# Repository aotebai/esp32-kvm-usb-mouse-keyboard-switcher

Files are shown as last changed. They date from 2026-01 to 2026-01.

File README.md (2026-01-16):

# ESP32-S3 KVM Switch (Dual-Device Keyboard & Mouse Sharing)

## 🌐 Language Switch
- [🔤 English Version (Current)](./README.md)
- [📝 中文版本](./docs/README_zh.md)

---
## 🔤 English-version
### 🚩Project Introduction
A dual-device KVM switch based on ESP32-S3 and CH9350 modules, which enables seamless sharing of a single set of keyboard and mouse between two computers. Equipped with ESP32-S3 on-board RGB-LED light effects to indicate the working status, no driver installation is required, and users without development experience can flash the precompiled firmware with one click. It supports dual-device power supply redundancy design to ensure stable system operation when a single device is powered on.
### ✨Key Features

- Dual-device switching: Supports fast switching of keyboard and mouse between 2 computers (shares one set of keyboard and mouse)
- Two switching methods: Mouse middle button (can be disabled via the K2 button of the 3-position microswitch) or K1 button of the 3-position microswitch
- LED effect indication: Three non-repeating colors of the LED flash in sequence during switching; a blue breathing light indicates Host A, and a red breathing light indicates Host B, with no flicker or abnormal extinction
- Complete core functions: Keyboard and mouse DMA transparent transmission, mouse middle button switching, K1 button switching of the 3-position microswitch, K2 button (on/off) for the mouse middle button function, K3 button short press to control the LED, long press to reset, and no functional degradation after standing idle
- Redundant power supply design: Achieves dual-device power supply mutual backup through Schottky diodes, ensuring stable system operation when a single device is powered on
- ESP-IDF compatibility: Compatible with ESP-IDF v5.5.1, no third-party dependencies, and only uses natively compatible APIs for stable operation
- Driver-free compatibility: Supports all operating systems (Windows/Mac/Linux) that support the USB HID protocol
- One-click flashing: Provides precompiled firmware, no need to build an ESP-IDF development environment

### 🛠️ Hardware List
| Hardware Name | Taobao Link | Quantity | Unit Price (CNY) | Total Amount (CNY) | Shipping Fee (CNY) | Grand Total (CNY) |
|:---:|:---:|:---:|:---:|:---:|:---:|:---:|
| ESP32 S3 Core Board (1-N16R8) | [ESP32 S3 Core Board Link](https://item.taobao.com/item.htm?id=715306783664) | 1 | 24.1 | 24.1 | 0 | 24.1 |
| CH9350 Module | [CH9350 Module Link](https://item.taobao.com/item.htm?id=695173316772) | 3 | 18.5 | 55.5 | 3 | 58.5 |
| 3-position Microswitch (with K1/K2/K3 Buttons) | [3-position Microswitch Link](https://item.taobao.com/item.htm?id=550176517768) | 1 | 3.88 | 3.88 | 0 | 3.88 |
| USB OTG Cable (Male to Male) | [USB OTG Cable Link](https://item.taobao.com/item.htm?id=550176517768) | 6 | 0.85 | 5.1 | 2 | 7.1 |
| Through-hole Schottky Diode DO-41 (1N5819 1A 40V) | [Through-hole Schottky Link](https://detail.tmall.com/item.htm?id=781535844592) | 20(use2) | 1.7 | 1.7 | 0 | 1.7 |
| 304 Stainless Steel Pan Head Screw and Nut Set(M2.5x8) | [Head Screw and Nut Set Link](https://detail.tmall.com/item.htm?id=637072501037) | 50(use14) | 4.7 | 4.7 | 0 | 4.7 |
| 3D Printed Case | [3D Printed Case Link](https://www.jlc-3dp.cn/fp/Amntaau/1) | 1 | 24.78 | 24.78 | 3.2 | 27.98 |

### 🔌 Wiring & Assembly

1.Connect the keyboard and mouse to the corresponding USB ports of the CH9350 module respectively

2.Connect the CH9350 module UART port (Host A) to ESP32-S3: TXD→U0RX (GPIO10), RXD→U0TX (GPIO11), GND→GND, 5V→1N5819→5V (ensure stable power supply)

3.Connect the CH9350 module UART port (Host B) to ESP32-S3: TXD→U2RX (GPIO44), RXD→U2TX (GPIO43), GND→GND, 5V→1N5819→5V (ensure stable power supply)

4.Wire the 3-position microswitch: Connect the K1/K2/K3 buttons to the corresponding GPIO pins of the ESP32-S3 respectively

5.Schottky diodes: The anodes of the two diodes are connected to the 5V pins of Host A and Host B respectively, and the cathodes are connected to the 5Vin of ESP32S3 and the 5V pin of Slave C (to ensure effective power supply when one computer is powered on and the entire system can run normally)

6.Organize all components and assemble them into the 3D printed case, fix them firmly to avoid poor contact

#### Wiring Diagrams
##### 1. Power Supply Wiring

      [Host A]                       [Host B]
          |                               |
        5V_OUT                           5V_OUT
          |                               |
          +-----> [D1] +-----+            +-----> [D2] +-----+
          |       (1N5819)   |            |       (1N5819)   |
          |       DO-41      |            |       DO-41      |
          |                  |            |                  |
          +------------------+------------+------------------+
                             |
                        [System 5V Bus]
                             |
                  +----------+-----------+
                  |                      |
            [ESP32S3]                [Slave C]
            5V (Vin)                 5V_IN
           
       [ESP32S3]   [Host A]   [Host B]   [Slave C]   [Microswitch]
          GND ------ GND ------- GND ------- GND ------ GND

##### 2. UART & Control Wiring
       [ESP32S3]                  [Host A]
       U0TX (GPIO11) ------------> RXD
       U0RX (GPIO10) <------------ TXD
       
       [ESP32S3]                  [Host B]
       U2TX (GPIO43) ------------> RXD  
       U2RX (GPIO44) <------------ TXD
       
       [ESP32S3]                  [Slave C]
       U1TX (GPIO17) ------------> TXD  
       U1RX (GPIO18) <------------ RXD
       
       [ESP32S3]                  [Microswitch]
       GPIO12 -------------------->(K1) 
       GPIO13 -------------------->(K2) 
       GPIO14 -------------------->(K3) 

### 🚀 One-Click Flashing (No ESP-IDF Required)
#### For Windows Users

1. Download the Espressif ESP Flash Download Tool (recommended to get the latest version from the official website):
   - 🔗 [Official ESP Flash Download Tool](https://docs.espressif.com/projects/esp-test-tools/en/latest/esp32/production_stage/tools/flash_download_tool.html)
   - 📦 [Local Mirror (flash_download_tool.zip)](./firmware/tools/flash_download_tool.zip) (for faster access, same as official latest version)
2. Connect the ESP32-S3 development board to the computer via a USB cable, and select the corresponding COM port (install the dedicated ESP32-S3 USB driver if it is not recognized)
3. Set the flashing parameters: 80MHz / DIO / 2MB (strictly correspond to the firmware configuration to avoid flashing failure)
4. Add firmware files and corresponding flashing addresses:
        - bootloader.bin @ 0x0
        - partition-table.bin @ 0x8000
        - ch9350_led_switch.bin @ 0x10000
5. Click the "START" button on the tool interface to start flashing, and wait for the progress bar to complete (the prompt "FINISH" indicates success)

For detailed address description and parameter verification: firmware/precompiled/flash_addresses.md
### 🎮 How to Use

1. Connect the ESP32-S3 to two target computers via USB cables respectively, ensuring the computers recognize the device normally (no driver prompt is required)
2. Device switching: Press the "mouse middle button" or "K1 button of the 3-position microswitch", the LED will flash three colors in sequence, and the corresponding host breathing light will turn on after completion (blue for Host A, red for Host B)
3. Mouse middle button function control: Press the "K2 button" to switch the on/off status of the mouse middle button switching function (it is recommended to use an LED indicator to distinguish the on/off status)
4. LED control and reset: Short press the "K3 button" to manually control the LED on/off; long press the "K3 button" for more than 3 seconds to reset the device to the initial state

### 🎨 3D Case & PDF Files

 - 3D Models: 3d_models/ (including FreeCAD source files and STL printing files, which can be directly used for 3D printing)
 - 2D Drawings: PDF_drawing/ (PDF formats, which can be used for Wiring Diagrams)

3D Case Rendering:

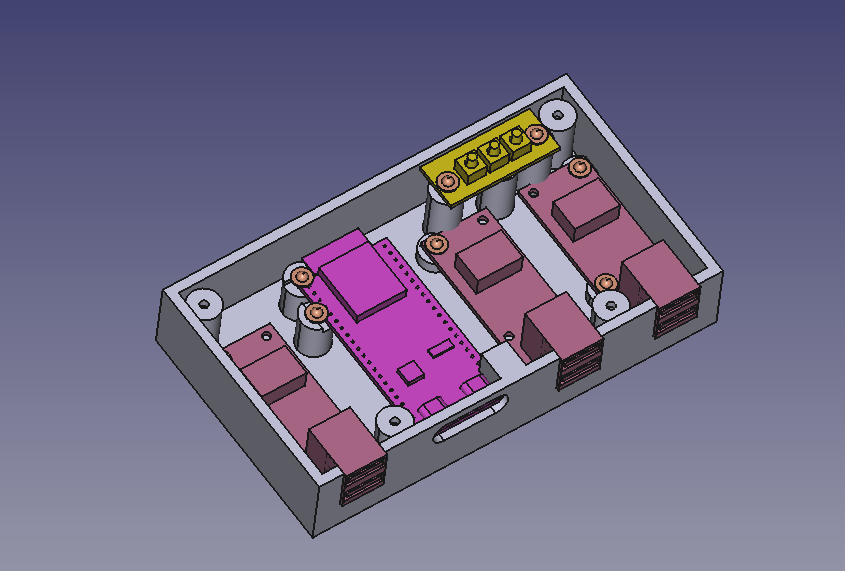
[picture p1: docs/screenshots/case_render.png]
3D Case Rendering


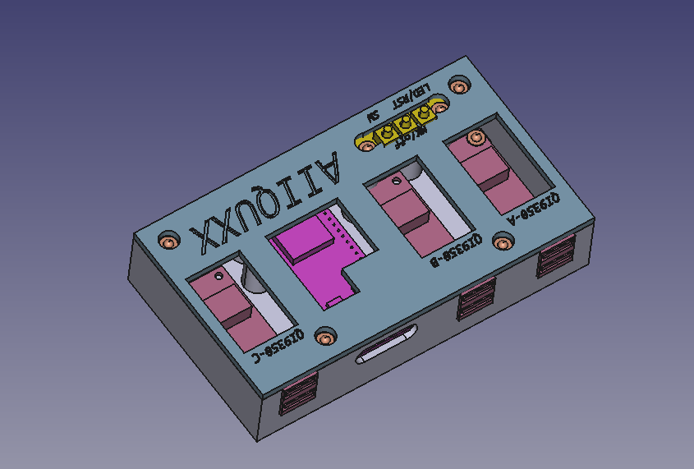
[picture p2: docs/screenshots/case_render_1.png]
3D Case Rendering_1


physical image:

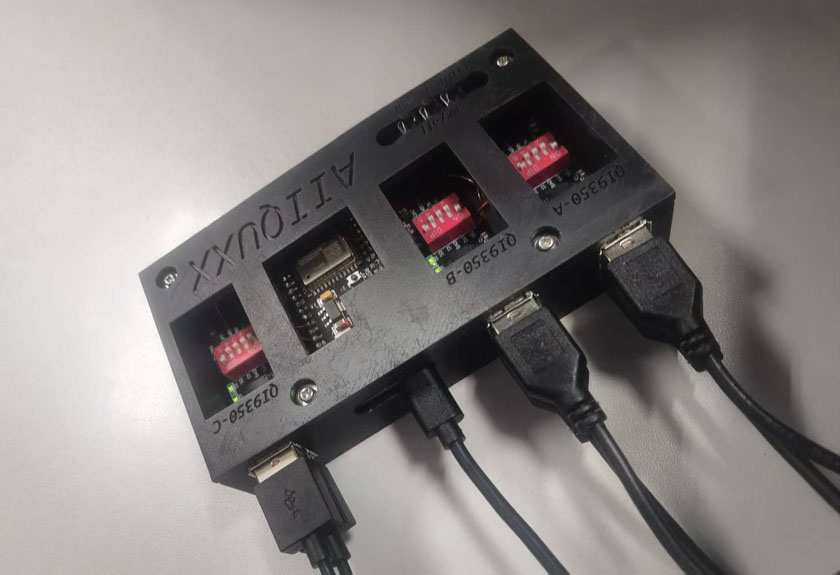
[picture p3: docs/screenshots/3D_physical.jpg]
physical image

### 🔨 Build from Source (For Developers)

1. Install ESP-IDF v5.5.1 (strictly correspond to the version to avoid compatibility issues)
2. clone repositoryto locate:    `git clone https://github.com/aotebai/esp32-kvm-usb-mouse-keyboard-switcher.git`
3. Enter the project directory and execute the following commands to compile and flash:
```bash
idf.py set-target esp32s3
idf.py build
idf.py -p /dev/ttyUSB0 flash monitor
```
### ❓ Frequently Asked Questions (FAQ)
Q1: Flashing failed / COM port not recognized

A: Install the corresponding USB driver for ESP32-S3; replace with a high-quality USB cable (avoid data cables that only charge without transmitting data); replace the USB port of the computer; ensure the development board enters download mode (operate according to the corresponding key combination).

Q2: No response after assembly, LED not on

A: Check the wiring (especially the power supply line and UART connection, avoid reversing pins); verify that the firmware flashing address is correct; ensure the CH9350 module receives stable 5V power supply and the ESP32-S3 power supply voltage is normal; check if the diode is reversed.

Q3: Switching function is normal, but the keyboard and mouse are not recognized by the computer

A: Confirm that the target computer recognizes the ESP32-S3 as a USB HID device (can be viewed in Device Manager); replace the USB port or USB cable of the computer; update to the latest version of the project firmware, and check whether the communication between the CH9350 module and ESP32-S3 is normal.

Q4: Abnormal LED light effects (flicker, wrong color)

A: Check whether the LED wiring is firm and the pins are corresponding correctly; confirm that the LED control logic in the firmware is consistent with the hardware wiring; try replacing the faulty LED.

Q5: The system cannot work when a single computer is powered on

A: Check if the diode wiring direction is correct (anode connected to host 5V, cathode connected to system bus); confirm that the diode model is 1N5819 (to ensure low forward conduction voltage); check if there is poor contact in the power supply line.

### 📺 Demo Video
Bilibili Demo Link (Waiting...)
### 📄 Open Source License
Apache License 2.0 ,See the [LICENSE](/LICENSE) file in the root directory for details.

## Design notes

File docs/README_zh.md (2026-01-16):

# ESP32-S3 KVM 切换器（双设备键鼠共享）

## 🌐 语言切换
- [📝 中文版本 (当前)](./docs/README_zh.md)
- [🔤 English Version](../README.md)

---

## 📝  中文版本

### 🚩 项目介绍
一款基于 ESP32-S3 和 CH9350 模块的双设备 KVM 切换器，可实现一套键鼠无缝共享给两台电脑，搭配ESP32-S3板载RGB-LED 灯光特效指示工作状态，无需安装驱动，无开发经验用户也可通过预编译固件一键烧录使用。支持双设备供电冗余设计，确保单设备开机时系统仍能稳定运行。

### ✨ 核心功能
- 双设备切换：支持 2 台电脑之间的键鼠快速切换（共享一套键盘和鼠标）
- 两种切换方式：鼠标中键（可通过三位微动开关的K2键禁用）或三位微动开关 K1 键
- 灯光特效指示：切换时 LED 三种不重复的颜色顺序爆闪、 蓝色呼吸灯特效指示上位机 A，红色呼吸灯特效指示上位机 B，无频闪、无熄灭异常
- 核心功能完整：键鼠 DMA 透传，鼠标中键切换，三位微动开关 K1 键切换，K2键（开/关）鼠标中间键功能，K3键短按控制 LED、长按复位，静置后无功能衰减
- 供电冗余设计：通过肖特基二极管实现双设备供电互备，单设备开机即可保障系统正常运行
- 开发环境兼容：兼容 ESP-IDF v5.5.1，无第三方依赖，仅使用原生兼容 API，运行稳定
- 免驱兼容：支持所有支持 USB HID 协议的操作系统（Windows/Mac/Linux）
- 一键烧录：提供预编译固件，无需搭建 ESP-IDF 开发环境

### 🛠️ 硬件清单
| 硬件名称 | 购买链接 | 数量 | 单价(元) | 金额(元) | 快递费(元) | 合计(元) |
|---|---|---|---|---|---|---|
| ESP32 S3 核心板（1-N16R8） | [ESP32 S3 核心板](https://item.taobao.com/item.htm?id=715306783664) | 1 | 24.1 | 24.1 | 0 | 24.1 |
| CH9350 模块 | [CH9350 模块](https://item.taobao.com/item.htm?id=695173316772) | 3 | 18.5 | 55.5 | 3 | 58.5 |
| 三位微动开关（含 K1/K2/K3 按键） | [三位微动开关](https://item.taobao.com/item.htm?id=550176517768) | 1 | 3.88 | 3.88 | 0 | 3.88 |
| USB OTG 线 (公对公) | [USB OTG 线](https://item.taobao.com/item.htm?id=550176517768) | 6 | 0.85 | 5.1 | 2 | 7.1 |
| 直插肖特基二极管DO-41(1N5819 1A 40V) | [直插肖特基二极管](https://detail.tmall.com/item.htm?id=781535844592) | 20(使用2个) | 1.7 | 1.7 | 0 | 1.7 |
| 304不锈钢十圆头螺丝螺母套装 (M2.5x8)| [圆头螺丝螺母套装](https://detail.tmall.com/item.htm?id=637072501037) | 50(使用14个) | 4.7 | 4.7 | 0 | 4.7 |
| 3D打印外壳 | [3D打印](https://www.jlc-3dp.cn/fp/Amntaau/1) | 1 | 24.78 | 24.78 | 3.2 | 27.98 |

### 🔌 接线与组装
1. 将键盘、鼠标分别连接至 CH9350 模块的对应 USB 接口
2. CH9350模块 UART口(上位机A) 与 ESP32-S3 连接：TXD→U0RX (GPIO10)、RXD→U0TX (GPIO11) 、GND→GND、5V→1N5819→5V（确保供电稳定）
3. CH9350模块 UART口(上位机B) 与 ESP32-S3 连接：TXD→U2RX (GPIO44)、RXD→U2TX (GPIO43) 、GND→GND、5V→1N5819→5V（确保供电稳定）
4. 三位微动开关接线：K1/K2/K3 按键分别连接至 ESP32-S3 对应的 GPIO 引脚
5. 肖特基二极管:两个二极管正极分别接上位机A、上位机B的5V引脚，负极接ESP32S3的5Vin和下位机C的5V引脚(确保在一台计算机开机的情况下有效供电，整个系统能正常运行)
6. 将所有部件整理后，组装至 3D 打印外壳中，固定牢固避免接触不良

#### 接线示意图
##### 1. 电源部分接线

       [上位机 A]                       [上位机 B]
          |                               |
        5V_OUT                           5V_OUT
          |                               |
          +-----> [D1] +-----+            +-----> [D2] +-----+
          |       (1N5819)   |            |       (1N5819)   |
          |       DO-41      |            |       DO-41      |
          |                  |            |                  |
          +------------------+------------+------------------+
                             |
                        [系统 5V 总线]
                             |
                  +----------+-----------+
                  |                      |
            [ESP32S3]                [下位机 C]
            5V (Vin)                 5V_IN
            
       [ESP32S3]   [上位机 A]   [上位机 B]   [下位机 C]   [微动开关]
          GND ------ GND ------- GND ------- GND ------ GND

    两个二极管正极分别接上位机 A、上位机 B 的 5V 引脚，负极汇接到系统 5V 总线
    系统 5V 总线为 ESP32S3 和下位机 C 供电，确保单台计算机开机时系统仍能正常运行

##### 2. 串口与控制部分接线

       [ESP32S3]                  [上位机 A]
       U0TX (GPIO11) ------------> RXD
       U0RX (GPIO10) <------------ TXD
       
       [ESP32S3]                  [上位机 B]
       U2TX (GPIO43) ------------> RXD  
       U2RX (GPIO44) <------------ TXD
       
       [ESP32S3]                   [下位机 C]  
       U1TX (GPIO17) ------------> TXD 
       U1RX (GPIO18) <------------ RXD

       [ESP32S3]                   [微动开关]
       GPIO12 -------------------->(K1) 
       GPIO13 -------------------->(K2) 
       GPIO14 -------------------->(K3) 

### 🚀 一键烧录（无需 ESP-IDF）
#### 适用于 Windows 用户
1. 下载乐鑫 ESP Flash Download Tool（选择对应系统版本，建议下载最新版）：
   - 🔗 [官方下载地址](https://docs.espressif.com/projects/esp-test-tools/zh_CN/latest/esp32/production_stage/tools/flash_download_tool.html)
   - 📦 [本地镜像（flash_download_tool.zip）](../firmware/tools/flash_download_tool.zip)（国内用户快速下载，与官方最新版一致）

2. 将 ESP32-S3 开发板通过 USB 线连接电脑，选择对应的 COM 口（未识别请安装 ESP32-S3 专用 USB 驱动）
3. 设置烧录参数：`80MHz` / `DIO` / `2MB`（严格对应固件配置，避免烧录失败）
4. 添加固件文件并对应烧录地址：
    - `bootloader.bin` @ `0x0`
    - `partition-table.bin` @ `0x8000`
    - `ch9350_led_switch.bin` @ `0x10000`
5. 点击工具界面「START」按钮开始烧录，等待进度条完成（提示“FINISH”即为成功）

详细地址说明及参数核对：`firmware/precompiled/flash_addresses.md`

### 🎮 使用方法
1. 通过 USB 线将 ESP32-S3 分别连接至两台目标电脑，确保电脑正常识别设备（无驱动提示即可）
2. 设备切换：按下「鼠标中键」或「三位微动开关 K1 键」，LED 三种颜色顺序爆闪，完成后对应上位机呼吸灯亮起（蓝色为上位机 A，红色为上位机 B）
3. 鼠标中键功能控制：按下「K2 键」可切换鼠标中键切换功能的开启/关闭（建议搭配 LED 指示灯区分开关状态）
4. LED 控制与复位：短按「K3 键」可手动控制 LED 灯光开关；长按「K3 键」3 秒以上，设备复位至初始状态

### 🎨 3D 外壳与 PDF 图纸
- 3D 模型：`3d_models/`（含 FreeCAD 源文件及 STL 打印文件，可直接用于 3D 打印）
- 2D 平面图：`PDF_drawing/`（PDF格式，可用于串口与控制部分接线）

3D 外壳渲染图：

3D 外壳渲染图

3D 外壳渲染图_1

实物图：

实物图
### 🔨 从源码编译（开发者专用）
1. 安装 ESP-IDF v5.5.1 版本（严格对应版本，避免兼容性问题）
2. 克隆本仓库至本地：`git clone https://github.com/aotebai/esp32-kvm-usb-mouse-keyboard-switcher.git`
3. 进入项目目录，执行以下命令编译、烧录：
```bash
idf.py set-target esp32s3
idf.py build
idf.py -p /dev/ttyUSB0 flash monitor
```

### ❓ 常见问题（FAQ）
Q1：烧录失败 / 无法识别 COM 口

A：安装 ESP32-S3 对应 USB 驱动；更换优质 USB 线（避免数据线仅充电不传输数据）；更换电脑 USB 端口；确保开发板进入下载模式（按对应按键组合操作）。

Q2：组装后设备无响应、LED 不亮

A：检查接线（尤其是供电线路和 UART 串口连接，避免接反引脚）；验证固件烧录地址是否正确；确保 CH9350 模块获得稳定 5V 供电，ESP32-S3 供电电压正常；检查二极管方向是否接反。

Q3：切换功能正常，但键鼠无法被电脑识别

A：确认目标电脑将 ESP32-S3 识别为 USB HID 设备（设备管理器中可查看）；更换电脑 USB 端口或 USB 线；更新至项目最新版本固件，检查 CH9350 模块与 ESP32-S3 通信是否正常。

Q4：LED 灯光特效异常（频闪、颜色错误）

A：检查 LED 灯珠接线是否牢固、引脚对应正确；确认固件中 LED 控制逻辑与硬件接线一致；更换故障 LED 灯珠尝试。

Q5：单台电脑开机时系统无法工作

A：检查二极管接线方向是否正确（正极接上位机 5V，负极接系统总线）；确认二极管型号为 1N5819（确保正向导通压降低）；检查供电线路是否存在接触不良。

### 📺 演示视频
B 站演示链接（正在制作中...）
### 📄 开源协议
Apache License 2.0, 详见根目录 [LICENSE](../LICENSE) 文件。

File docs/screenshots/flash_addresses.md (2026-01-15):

# ESP32-S3 Flash Burn Addresses
## 📋 Core Flash Burn Address List (Mandatory)
|Firmware File Name | Corresponding Burn Address | Notes |
|---|---|---|
|bootloader.bin | 0x0 | Bootloader, essential for ESP32-S3 startup |
|partition-table.bin | 0x8000 | Partition table, defines storage ranges for firmware, data, and other partitions |
|ch9350_led_switch.bin | 0x10000 | Project core firmware (implements KVM switch functionality) |
|nvs_partition.bin (Optional) | 0x9000 | NVS (Non-Volatile Storage) partition, used to save device configuration parameters|
## ⚙️ Mandatory Flash Burn Parameter Configuration
In addition to matching the addresses, the following parameters must also be consistent; otherwise, it will result in flash failure or device startup failure:

1. Crystal Oscillator Frequency: 80MHz (Recommended default value for ESP32-S3, do not change to 40MHz)
2. Flash Mode: DIO (Compatible with most ESP32-S3 development board flash memory, avoid using QIO mode)
3. Flash Size: 2MB (If your development board has 4MB/8MB flash memory, you can select the corresponding size, and the partition table needs to be adapted synchronously)
4. Baud Rate: 115200 (Stable transmission; excessively high baud rate may cause transmission errors, while excessively low baud rate will result in long flash time)

## 🚨 Important Notes

1.  The burn addresses of all firmware files cannot be modified arbitrarily; they must be consistent with the partition table configuration during compilation, otherwise the device cannot start normally.
2.  If you recompile the firmware using ESP-IDF, ensure that the addresses in the partition.csv partition table file are consistent with this document.
3.  During flashing, follow the sequence of "select the address first → then add the corresponding firmware file" to avoid mismatching files and addresses.
4.  If you receive prompts such as "startup failure" or "partition table error" after flashing, first check whether the address configuration and flash size parameters are correct.

## 📎 Related Documents

    ESP32-S3 Official Partition Table Documentation
    Project Flashing Tutorial: Root directory README.md (English) / docs/README_zh.md (Chinese)

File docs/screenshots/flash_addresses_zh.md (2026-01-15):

# ESP32-S3 Flash Burn Addresses (烧录地址说明)
## 📋 核心烧录地址清单（必看）
| 固件文件名称 | 对应烧录地址 | 备注说明 |
|---|---|---|
| `bootloader.bin` | `0x0` | 引导加载程序，ESP32-S3 启动必备 |
| `partition-table.bin` | `0x8000` | 分区表，定义固件、数据等分区的存储范围 |
| `ch9350_led_switch.bin` | `0x10000` | 项目核心固件（KVM 切换器功能实现） |
| `nvs_partition.bin`（可选） | `0x9000` | NVS 非易失性存储分区，用于保存设备配置参数 |

## ⚙️ 必选烧录参数配置
除了地址匹配，还需确保以下参数一致，否则会导致烧录失败或设备无法启动：
1.  **晶振频率**：`80MHz`（ESP32-S3 推荐默认值，不可改为 40MHz）
2.  **闪存模式**：`DIO`（兼容大多数 ESP32-S3 开发板闪存，避免使用 QIO 模式）
3.  **闪存大小**：`2MB`（若你的开发板闪存为 4MB/8MB，可选择对应大小，分区表需同步适配）
4.  **波特率**：`115200`（稳定传输，过高易出现传输错误，过低烧录耗时过长）

## 🚨 注意事项
1.  所有固件文件的烧录地址**不可随意修改**，必须与编译时的分区表配置一致，否则设备无法正常启动；
2.  若使用 ESP-IDF 重新编译固件，需确保 `partition.csv` 分区表文件中的地址与本文档一致；
3.  烧录时需按「先选择地址 → 再添加对应固件文件」的顺序操作，避免文件与地址不匹配；
4.  若烧录后提示「启动失败」「分区表错误」，优先检查地址配置和闪存大小参数是否正确。

## 📎 关联文档
- [ESP32-S3 官方分区表说明](https://docs.espressif.com/projects/esp-idf/en/latest/esp32s3/api-guides/partition-tables.html)
- 项目烧录教程：根目录 `README.md`（英文）/ `docs/README_zh.md`（中文）

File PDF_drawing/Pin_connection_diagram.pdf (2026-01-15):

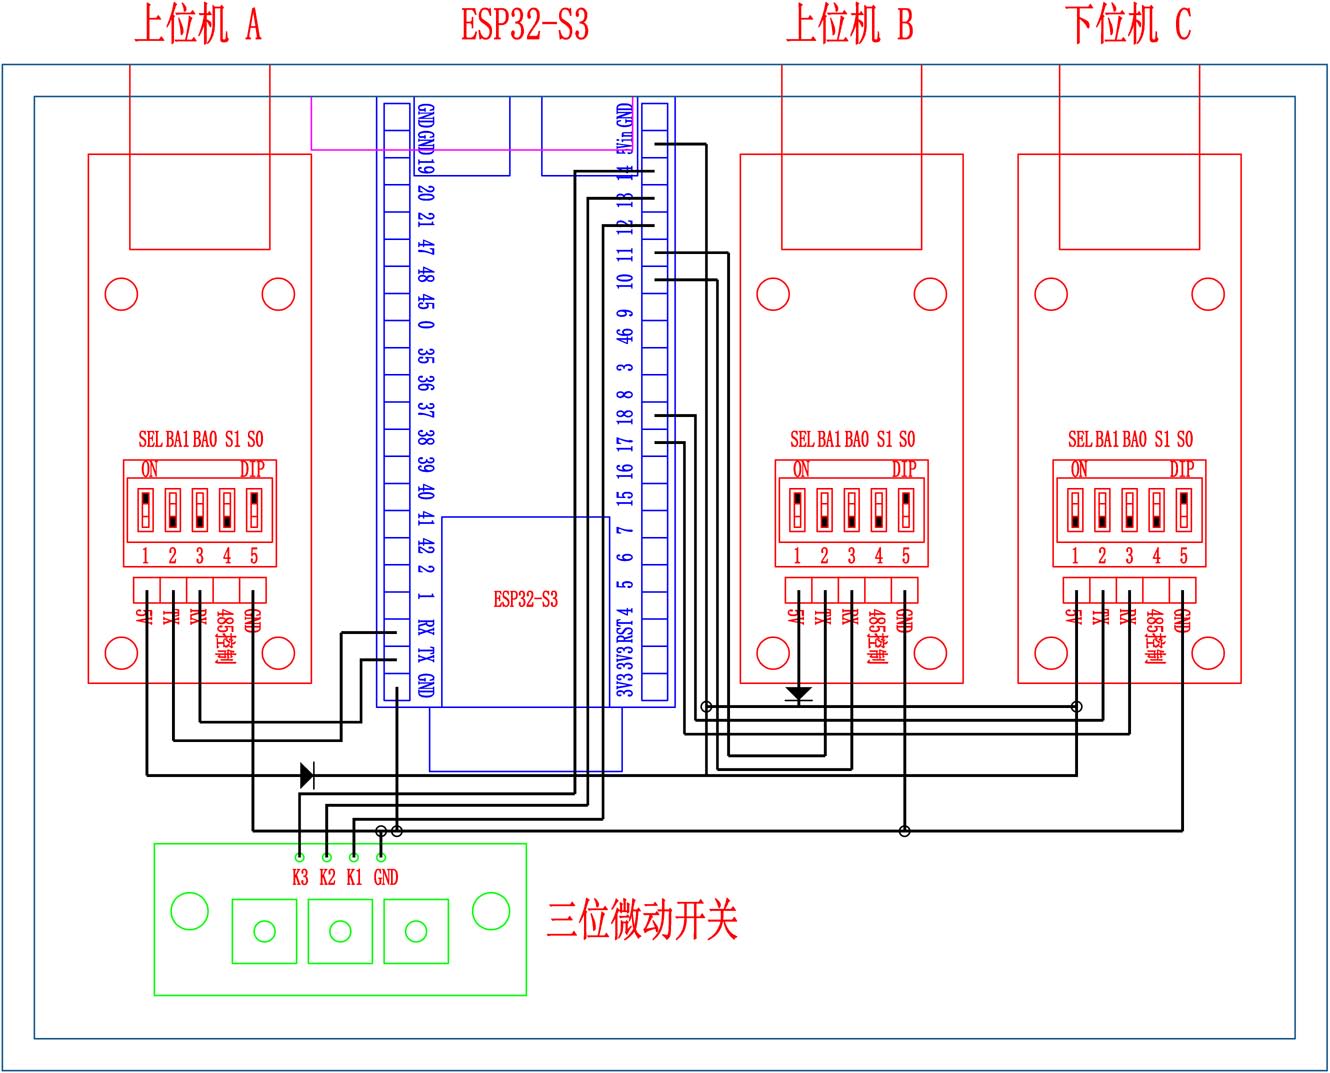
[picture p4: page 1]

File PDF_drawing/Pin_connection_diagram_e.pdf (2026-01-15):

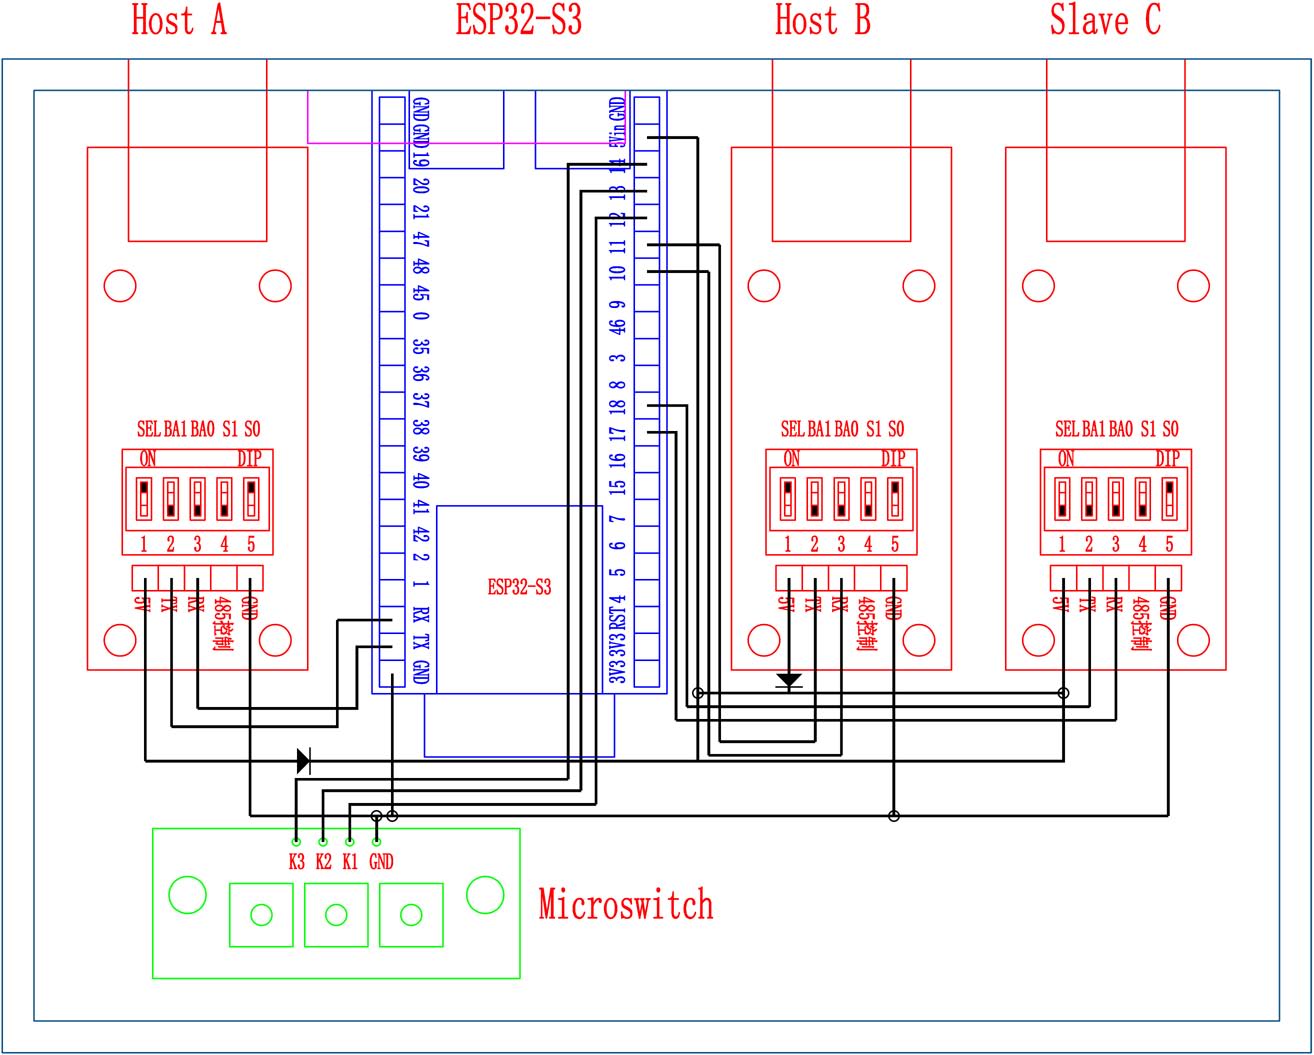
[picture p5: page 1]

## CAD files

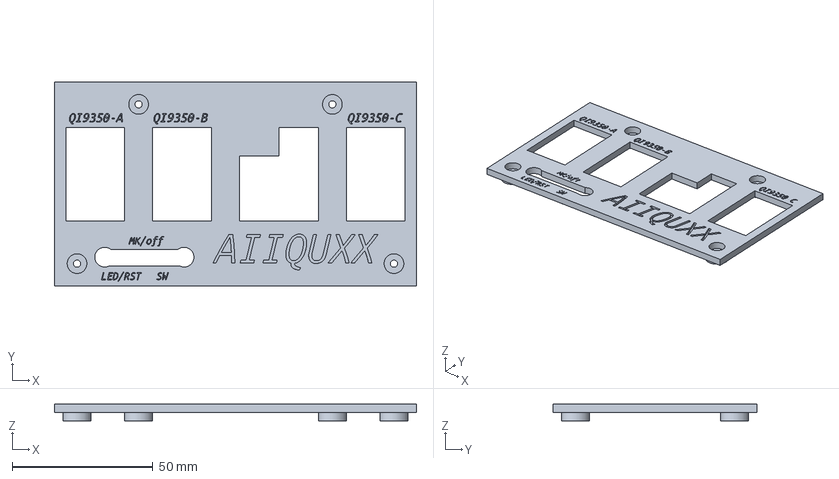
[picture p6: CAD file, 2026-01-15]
3d_models/box_cover_1.FCStd
128.5 x 72.5 x 6.00 mm

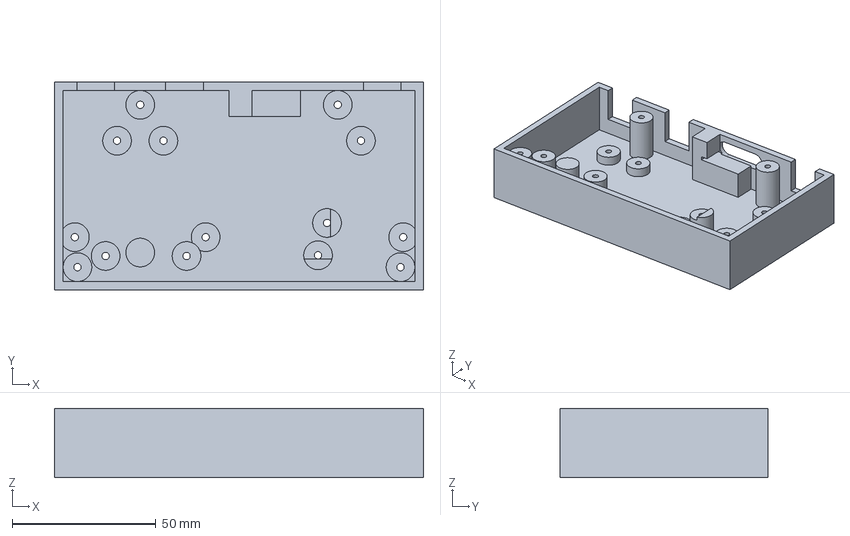
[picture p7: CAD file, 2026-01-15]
3d_models/box.FCStd
128.5 x 72.6 x 24.1 mm

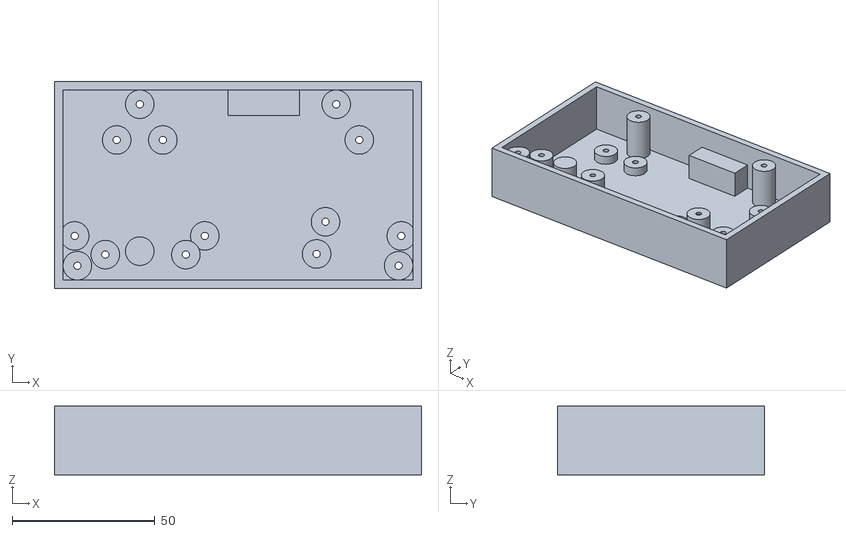
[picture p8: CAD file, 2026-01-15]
3d_models/box-Pocket008 (Meshed).stl
128.5 x 72.6 x 24.1

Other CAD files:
3d_models/box_cover_1-Pocket008 (Meshed)001.stl

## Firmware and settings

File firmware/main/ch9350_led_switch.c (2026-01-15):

#include <stdio.h>
#include <string.h>
#include <math.h>
#include "freertos/FreeRTOS.h"
#include "freertos/task.h"
#include "freertos/semphr.h"
#include "driver/uart.h"
#include "driver/gpio.h"
#include "driver/rmt.h"
#include "esp_log.h"
#include "esp_timer.h"
#include "esp_random.h"
#include "esp_system.h"
#include "esp_rom_sys.h" // 新增：硬件延时头文件

// ==================== 核心配置参数 ====================
// UART配置
#define BAUD_RATE          115200
#define FRAME_LENGTH       7
#define SWITCH_LOCKOUT_MS  1500

// DMA配置
#define UART_DMA_BUFF_SIZE     256
#define UART_DMA_RX_TIMEOUT    1
#define UART_DMA_RX_THRESHOLD  (UART_DMA_BUFF_SIZE / 2)

// UART端口与引脚
#define UART_LOWER_NUM     UART_NUM_1
#define UART_UPPER_A_NUM   UART_NUM_0
#define UART_UPPER_B_NUM   UART_NUM_2

#define UART_LOWER_TXD     17
#define UART_LOWER_RXD     18
#define UART_UPPER_A_TXD   11
#define UART_UPPER_A_RXD   10
#define UART_UPPER_B_TXD   43
#define UART_UPPER_B_RXD   44

// 微动开关引脚
#define K1_GPIO            12
#define K2_GPIO            13
#define K3_GPIO            14

// K3长按复位配置
#define K3_LONG_PRESS_MS   3000    // 长按3秒触发复位
#define K3_DEBOUNCE_MS     50      // 消抖时间

// 鼠标中键帧解析
#define MOUSE_FRAME_HEADER1 0x57
#define MOUSE_FRAME_HEADER2 0xAB
#define MOUSE_OPCODE       0x02
#define MOUSE_BUTTON_BYTE  3
#define MIDDLE_BUTTON_BIT  2

// WS2812配置
#define LED_STRIP_GPIO_PIN         48
#define LED_STRIP_LED_COUNT        1
#define RMT_RESOLUTION_HZ          10000000
#define RMT_CHANNEL                RMT_CHANNEL_0

// 爆闪参数
#define BURST_TIMES_PER_COLOR      10
#define BURST_FLASH_PERIOD_US      80000
#define BURST_ON_US                40000
#define PAUSE_MS_BETWEEN_COLOR     50
#define BURST_SELECT_COLOR_NUM     3

// 呼吸灯参数
#define BREATH_FREQ_PER_MIN        7.5f
#define BREATH_PERIOD_MS           (uint32_t)(2 * 60 * 1000 / BREATH_FREQ_PER_MIN)
#define BREATH_STEP_MS             10
#define BREATH_MAX_BRIGHTNESS      155
#define BREATH_SMOOTH_FACTOR       2.0f
#define BREATH_DARK_OFF_MS         500

// WS2812时序
#define WS2812_T0H_TICKS           (uint16_t)(0.4 * RMT_RESOLUTION_HZ / 1000000)
#define WS2812_T0L_TICKS           (uint16_t)(0.85 * RMT_RESOLUTION_HZ / 1000000)
#define WS2812_T1H_TICKS           (uint16_t)(0.8 * RMT_RESOLUTION_HZ / 1000000)
#define WS2812_T1L_TICKS           (uint16_t)(0.45 * RMT_RESOLUTION_HZ / 1000000)
#define WS2812_RESET_TICKS         (uint16_t)(50 * RMT_RESOLUTION_HZ / 1000000)

// ==================== 类型定义 ====================
// 连接状态
typedef enum {
    CONNECTED_TO_A,
    CONNECTED_TO_B
} ConnectionState;

// 呼吸灯颜色
typedef enum {
    BREATH_COLOR_RED,
    BREATH_COLOR_BLUE
} BreathColor;

// RGB颜色结构
typedef struct {
    uint8_t r;
    uint8_t g;
    uint8_t b;
} rgb_color_t;

// ==================== 全局变量 ====================
static const char *TAG = "ch9350_led_switch";

// 连接状态
static ConnectionState currentState = CONNECTED_TO_A;
static volatile uint64_t lastSwitchTime = 0;
static volatile bool mouse_middle_enable = true;
// LED功能总开关
static volatile bool led_function_enable = true;

// K3长按检测变量
static volatile uint64_t k3_press_start_time = 0;
static volatile bool k3_is_pressed = false;

// 同步信号量/标志
static SemaphoreHandle_t switchSemaphore = NULL;
static SemaphoreHandle_t ledSemaphore = NULL;
static volatile gpio_num_t triggerGpio = GPIO_NUM_NC;
static volatile BreathColor currentBreathColor = BREATH_COLOR_BLUE;
static volatile bool led_stop_flag = false; // 呼吸灯停止标志

// UART队列
static QueueHandle_t uart_lower_queue = NULL;
static QueueHandle_t uart_upper_a_queue = NULL;
static QueueHandle_t uart_upper_b_queue = NULL;

// LED颜色池
static const rgb_color_t burst_color_pool[] = {
    {255, 0, 0},     // 红
    {255, 165, 0},   // 橙
    {255, 255, 0},   // 黄
    {0, 255, 0},     // 绿
    {0, 0, 255},     // 蓝
    {255, 0, 255},   // 紫
    {255, 255, 255}  // 白
};
#define BURST_POOL_COUNT (sizeof(burst_color_pool) / sizeof(rgb_color_t))

// ==================== 函数声明 ====================
// UART相关
static uart_port_t getActiveUpperUart(void);
static QueueHandle_t getActiveUpperUartQueue(void);
static void uart_config(void);
static void handleUartInterruptEvent(QueueHandle_t uart_queue, uart_port_t src_uart, uart_port_t dest_uart);
static void uart_forward_task(void *arg); // 新增：UART转发独立任务

// 切换逻辑
static void switchConnection(void);
static void toggleMouseMiddleFunc(void);
static void toggleLedFunction(void);
static bool parseMouseFrame(uint8_t *frame, int len);

// GPIO中断
static void IRAM_ATTR gpio_isr_handler(void *arg);
static void gpio_interrupt_config(void);

// K3长按检测
static void k3_long_press_detect_task(void *arg);

// LED相关
static esp_err_t rmt_ws2812_init(void);
static void ws2812_color_to_rmt_items(uint8_t r, uint8_t g, uint8_t b, rmt_item32_t *items, size_t *item_num);
static void rmt_send_ws2812_color(uint8_t r, uint8_t g, uint8_t b);
static void burst_select_random_colors(rgb_color_t *selected_colors, size_t select_num);
static void burst_flash_random_3color(void);
static void breath_light_loop(BreathColor color);
static void led_control_task(void *arg);

// ==================== UART配置 ====================
static void uart_config() {
    uart_config_t cfg = {
        .baud_rate = BAUD_RATE,
        .data_bits = UART_DATA_8_BITS,
        .parity = UART_PARITY_DISABLE,
        .stop_bits = UART_STOP_BITS_1,
        .flow_ctrl = UART_HW_FLOWCTRL_DISABLE,
        .source_clk = UART_SCLK_DEFAULT,
    };

    // 下位机UART
    uart_param_config(UART_LOWER_NUM, &cfg);
    uart_set_pin(UART_LOWER_NUM, UART_LOWER_TXD, UART_LOWER_RXD, UART_PIN_NO_CHANGE, UART_PIN_NO_CHANGE);
    uart_driver_install(
        UART_LOWER_NUM,
        UART_DMA_BUFF_SIZE,
        UART_DMA_BUFF_SIZE,
        10,
        &uart_lower_queue,
        0
    );
    uart_set_rx_timeout(UART_LOWER_NUM, UART_DMA_RX_TIMEOUT);
    uart_set_rx_full_threshold(UART_LOWER_NUM, UART_DMA_RX_THRESHOLD);
    uart_flush_input(UART_LOWER_NUM);

    // 上位机A UART
    uart_param_config(UART_UPPER_A_NUM, &cfg);
    uart_set_pin(UART_UPPER_A_NUM, UART_UPPER_A_TXD, UART_UPPER_A_RXD, UART_PIN_NO_CHANGE, UART_PIN_NO_CHANGE);
    uart_driver_install(
        UART_UPPER_A_NUM,
        UART_DMA_BUFF_SIZE,
        UART_DMA_BUFF_SIZE,
        10,
        &uart_upper_a_queue,
        0
    );
    uart_set_rx_timeout(UART_UPPER_A_NUM, UART_DMA_RX_TIMEOUT);
    uart_set_rx_full_threshold(UART_UPPER_A_NUM, UART_DMA_RX_THRESHOLD);
    uart_flush_input(UART_UPPER_A_NUM);

    // 上位机B UART
    uart_param_config(UART_UPPER_B_NUM, &cfg);
    uart_set_pin(UART_UPPER_B_NUM, UART_UPPER_B_TXD, UART_UPPER_B_RXD, UART_PIN_NO_CHANGE, UART_PIN_NO_CHANGE);
    uart_driver_install(
        UART_UPPER_B_NUM,
        UART_DMA_BUFF_SIZE,
        UART_DMA_BUFF_SIZE,
        10,
        &uart_upper_b_queue,
        0
    );
    uart_set_rx_timeout(UART_UPPER_B_NUM, UART_DMA_RX_TIMEOUT);
    uart_set_rx_full_threshold(UART_UPPER_B_NUM, UART_DMA_RX_THRESHOLD);
    uart_flush_input(UART_UPPER_B_NUM);

    ESP_LOGI(TAG, "UART（DMA模式）初始化完成");
}

// ==================== 连接切换逻辑 ====================
static void switchConnection() {
    uint64_t t = esp_timer_get_time() / 1000;
    if (t - lastSwitchTime <= SWITCH_LOCKOUT_MS) return;
    lastSwitchTime = t;

    // 1. 立即停止当前呼吸灯
    led_stop_flag = true;
    rmt_send_ws2812_color(0, 0, 0); // 强制熄灭LED
    vTaskDelay(pdMS_TO_TICKS(10));  // 确保停止信号生效

    // 2. 切换连接状态
    ConnectionState oldState = currentState;
    currentState = (currentState == CONNECTED_TO_A) ? CONNECTED_TO_B : CONNECTED_TO_A;
    const char* target = (currentState == CONNECTED_TO_A) ? "上位机A" : "上位机B";

    // 3. 设置新呼吸灯颜色
    currentBreathColor = (currentState == CONNECTED_TO_A) ? BREATH_COLOR_BLUE : BREATH_COLOR_RED;

    // 4. 清空UART缓冲区
    uart_flush_input(getActiveUpperUart());
    uart_flush_input(UART_LOWER_NUM);

    ESP_LOGI(TAG, "[K1/中键] 切换到 %s，呼吸灯颜色：%s", 
             target, 
             (currentBreathColor == BREATH_COLOR_RED) ? "红色" : "蓝色");

    // 5. 触发LED任务（执行新特效）
    xSemaphoreGive(ledSemaphore);
}

static void toggleMouseMiddleFunc() {
    uint64_t t = esp_timer_get_time() / 1000;
    if (t - lastSwitchTime <= SWITCH_LOCKOUT_MS) return;
    lastSwitchTime = t;

    mouse_middle_enable = !mouse_middle_enable;
    ESP_LOGI(TAG, "鼠标中键功能 → %s", mouse_middle_enable ? "开启" : "关闭");
}

// K3键控制LED功能启停
static void toggleLedFunction() {
    uint64_t t = esp_timer_get_time() / 1000;
    if (t - lastSwitchTime <= SWITCH_LOCKOUT_MS) return;
    lastSwitchTime = t;

    led_function_enable = !led_function_enable;
    if (!led_function_enable) {
        // 关闭时停止所有LED特效并熄灭
        led_stop_flag = true;
        rmt_send_ws2812_color(0, 0, 0);
        ESP_LOGI(TAG, "LED特效功能 → 关闭（爆闪/呼吸灯均禁用）");
    } else {
        // 开启时恢复当前呼吸灯
        ESP_LOGI(TAG, "LED特效功能 → 开启（恢复%s呼吸灯）", 
                 (currentBreathColor == BREATH_COLOR_RED) ? "红色" : "蓝色");
        xSemaphoreGive(ledSemaphore);
    }
}

// ==================== 鼠标帧解析 ====================
static bool parseMouseFrame(uint8_t *frame, int len) {
    if (!mouse_middle_enable) return false;

    if (len != FRAME_LENGTH ||
        frame[0] != MOUSE_FRAME_HEADER1 ||
        frame[1] != MOUSE_FRAME_HEADER2 ||
        frame[2] != MOUSE_OPCODE) {
        return false;
    }

    if (((frame[MOUSE_BUTTON_BYTE] >> MIDDLE_BUTTON_BIT) & 0x01) == 1) {
        ESP_LOGD(TAG, "[鼠标中键触发] 中键按下 → 切换上位机（此帧不转发）");
        switchConnection();
        return true;
    }

    return false;
}

// ==================== GPIO中断 ====================
static void IRAM_ATTR gpio_isr_handler(void *arg) {
    gpio_num_t gpio = (gpio_num_t)arg;
    // 支持K1/K2/K3_GPIO中断
    if (gpio != K1_GPIO && gpio != K2_GPIO && gpio != K3_GPIO) return;

    uint64_t now = esp_timer_get_time() / 1000;

    // K3按键单独处理：记录按下/释放时间
    if (gpio == K3_GPIO) {
        if (gpio_get_level(K3_GPIO) == 0) { // 按下（低电平）
            k3_press_start_time = now;
            k3_is_pressed = true;
        } else { // 释放（高电平）
            // 短按：触发LED启停（需消抖）
            if (k3_is_pressed && (now - k3_press_start_time) < K3_LONG_PRESS_MS && (now - k3_press_start_time) > K3_DEBOUNCE_MS) {
                triggerGpio = K3_GPIO; // 标记为短按事件
                BaseType_t hp = pdFALSE;
                xSemaphoreGiveFromISR(switchSemaphore, &hp);
                if (hp) portYIELD_FROM_ISR();
            }
            k3_is_pressed = false;
            k3_press_start_time = 0;
        }
        return;
    }

    // K1/K2正常处理
    triggerGpio = gpio;
    BaseType_t hp = pdFALSE;
    xSemaphoreGiveFromISR(switchSemaphore, &hp);
    if (hp) portYIELD_FROM_ISR();
}

static void gpio_interrupt_config() {
    gpio_config_t io = {
        .pin_bit_mask = (1ULL << K1_GPIO) | (1ULL << K2_GPIO) | (1ULL << K3_GPIO),
        .mode = GPIO_MODE_INPUT,
        .pull_up_en = GPIO_PULLUP_ENABLE,
        .intr_type = GPIO_INTR_ANYEDGE // 双边沿触发（检测按下/释放）
    };
    gpio_config(&io);

    switchSemaphore = xSemaphoreCreateBinary();
    gpio_install_isr_service(0);

    gpio_isr_handler_add(K1_GPIO, gpio_isr_handler, (void*)K1_GPIO);
    gpio_isr_handler_add(K2_GPIO, gpio_isr_handler, (void*)K2_GPIO);
    gpio_isr_handler_add(K3_GPIO, gpio_isr_handler, (void*)K3_GPIO);

    ESP_LOGI(TAG, "K按键中断配置完成（K1/K2/K3均已配置）");
}

// ==================== K3长按检测任务 ====================
static void k3_long_press_detect_task(void *arg) {
    while (1) {
        if (k3_is_pressed) {
            uint64_t now = esp_timer_get_time() / 1000;
            // 长按3秒触发复位
            if (now - k3_press_start_time >= K3_LONG_PRESS_MS) {
                ESP_LOGI(TAG, "K3长按3秒 → 触发系统复位！");
                rmt_send_ws2812_color(255, 0, 0); // 复位前闪红灯提示
                esp_rom_delay_us(500000); // 硬件延时500ms（不依赖FreeRTOS调度）
                esp_restart(); // 系统复位（等效RST按键）
            }
        }
        vTaskDelay(pdMS_TO_TICKS(100)); // 100ms检测一次，降低CPU占用
    }
    vTaskDelete(NULL);
}

// ==================== UART事件处理 ====================
static void handleUartInterruptEvent(QueueHandle_t uart_queue,
                                     uart_port_t src_uart,
                                     uart_port_t dest_uart) {
    uart_event_t event;
    uint8_t buf[UART_DMA_BUFF_SIZE];
    int len;

    if (xQueueReceive(uart_queue, &event, 0)) {
        switch (event.type) {
            case UART_DATA:
                len = uart_read_bytes(src_uart, buf, event.size, pdMS_TO_TICKS(10));
                if (len > 0) {
                    bool block = false;

                    if (src_uart == UART_LOWER_NUM) {
                        int pos = 0;
                        while (pos + FRAME_LENGTH <= len) {
                            block = parseMouseFrame(&buf[pos], FRAME_LENGTH);
                            if (block) {
                                pos += FRAME_LENGTH;
                                ESP_LOGD(TAG, "[阻止] 中键帧已被丢弃，不转发");
                                block = true;
                            } else {
                                uart_write_bytes(dest_uart, (const char*)&buf[pos], FRAME_LENGTH);
                                pos += FRAME_LENGTH;
                            }
                        }
                        if (pos < len && !block) {
                            uart_write_bytes(dest_uart, (const char*)&buf[pos], len - pos);
                        }
                    } else {
                        uart_write_bytes(dest_uart, (const char*)buf, len);
                    }
                }
                break;

            case UART_FIFO_OVF:
                ESP_LOGE(TAG, "UART(%d) FIFO溢出！清空缓冲区", src_uart);
                uart_flush_input(src_uart);
                xQueueReset(uart_queue);
                break;

            case UART_BUFFER_FULL:
                ESP_LOGE(TAG, "UART(%d)缓冲区满！清空缓冲区", src_uart);
                uart_flush_input(src_uart);
                xQueueReset(uart_queue);
                break;

            default:
                break;
        }
    }
}

// ==================== 新增：UART转发独立任务 ====================
static void uart_forward_task(void *arg) {
    (void)arg; // 未使用参数
    while (1) {
        // 处理下位机→当前激活的上位机
        handleUartInterruptEvent(uart_lower_queue, UART_LOWER_NUM, getActiveUpperUart());
        // 处理当前激活的上位机→下位机
        handleUartInterruptEvent(getActiveUpperUartQueue(), getActiveUpperUart(), UART_LOWER_NUM);
        // 低频率轮询，降低CPU占用
        vTaskDelay(pdMS_TO_TICKS(2));
    }
    vTaskDelete(NULL);
}

// ==================== 辅助函数 ====================
static uart_port_t getActiveUpperUart() {
    return (currentState == CONNECTED_TO_A) ? UART_UPPER_A_NUM : UART_UPPER_B_NUM;
}

static QueueHandle_t getActiveUpperUartQueue() {
    return (currentState == CONNECTED_TO_A) ? uart_upper_a_queue : uart_upper_b_queue;
}

// ==================== WS2812 LED控制 ====================
static esp_err_t rmt_ws2812_init(void) {
    rmt_config_t rmt_cfg = {
        .rmt_mode = RMT_MODE_TX,
        .channel = RMT_CHANNEL,
        .gpio_num = LED_STRIP_GPIO_PIN,
        .clk_div = 80 / (RMT_RESOLUTION_HZ / 1000000),
        .mem_block_num = 1,
        .tx_config = {
            .carrier_freq_hz = 38000,
            .carrier_level = RMT_CARRIER_LEVEL_HIGH,
            .carrier_en = false,
            .loop_en = false,
            .idle_level = RMT_IDLE_LEVEL_LOW,
            .idle_output_en = true,
        },
    };
    ESP_ERROR_CHECK(rmt_config(&rmt_cfg));
    ESP_ERROR_CHECK(rmt_driver_install(rmt_cfg.channel, 0, 0));

    return ESP_OK;
}

static void ws2812_color_to_rmt_items(uint8_t r, uint8_t g, uint8_t b, rmt_item32_t *items, size_t *item_num) {
    *item_num = 24;
    uint32_t grb = (g << 16) | (r << 8) | b;

    for (int i = 0; i < 24; i++) {
        uint32_t bit = (grb >> (23 - i)) & 0x1;
        if (bit) {
            items[i].level0 = 1;
            items[i].duration0 = WS2812_T1H_TICKS;
            items[i].level1 = 0;
            items[i].duration1 = WS2812_T1L_TICKS;
        } else {
            items[i].level0 = 1;
            items[i].duration0 = WS2812_T0H_TICKS;
            items[i].level1 = 0;
            items[i].duration1 = WS2812_T0L_TICKS;
        }
    }

    items[24].level0 = 0;
    items[24].duration0 = WS2812_RESET_TICKS;
    items[24].level1 = 0;
    items[24].duration1 = 0;
    *item_num += 1;
}

static void rmt_send_ws2812_color(uint8_t r, uint8_t g, uint8_t b) {
    rmt_item32_t items[25];
    size_t item_num = 0;

    ws2812_color_to_rmt_items(r, g, b, items, &item_num);
    ESP_ERROR_CHECK(rmt_write_items(RMT_CHANNEL, items, item_num, true));
    rmt_wait_tx_done(RMT_CHANNEL, portMAX_DELAY);
}

static void burst_select_random_colors(rgb_color_t *selected_colors, size_t select_num) {
    if (select_num > BURST_POOL_COUNT) {
        select_num = BURST_POOL_COUNT;
    }

    uint8_t indices[BURST_POOL_COUNT];
    for (int i = 0; i < BURST_POOL_COUNT; i++) {
        indices[i] = i;
    }

    for (int i = BURST_POOL_COUNT - 1; i > 0; i--) {
        uint8_t j = esp_random() % (i + 1);
        uint8_t temp = indices[i];
        indices[i] = indices[j];
        indices[j] = temp;
    }

    for (int i = 0; i < select_num; i++) {
        selected_colors[i] = burst_color_pool[indices[i]];
    }
}

static void burst_flash_random_3color(void) {
    // LED功能关闭时直接返回
    if (!led_function_enable) return;
    
    rgb_color_t selected_colors[BURST_SELECT_COLOR_NUM];
    burst_select_random_colors(selected_colors, BURST_SELECT_COLOR_NUM);

    // 爆闪前先熄灭
    rmt_send_ws2812_color(0, 0, 0);

    for (uint8_t color_idx = 0; color_idx < BURST_SELECT_COLOR_NUM; color_idx++) {
        rgb_color_t current_color = selected_colors[color_idx];

        for (int i = 0; i < BURST_TIMES_PER_COLOR; i++) {
            // 执行中检测开关状态
            if (!led_function_enable) {
                rmt_send_ws2812_color(0, 0, 0);
                return;
            }
            rmt_send_ws2812_color(current_color.r, current_color.g, current_color.b);
            vTaskDelay(pdMS_TO_TICKS(BURST_ON_US / 1000));

            rmt_send_ws2812_color(0, 0, 0);
            vTaskDelay(pdMS_TO_TICKS((BURST_FLASH_PERIOD_US - BURST_ON_US) / 1000));
        }

        if (color_idx < BURST_SELECT_COLOR_NUM - 1) {
            vTaskDelay(pdMS_TO_TICKS(PAUSE_MS_BETWEEN_COLOR));
        }
    }
}

// 循环呼吸灯（持续运行直到收到停止标志）
static void breath_light_loop(BreathColor color) {
    // LED功能关闭时直接返回
    if (!led_function_enable) return;
    
    const uint32_t total_steps = (BREATH_PERIOD_MS / BREATH_STEP_MS) / 2;
    const float rad_step = M_PI / total_steps;
    uint8_t last_bright = 0;

    // 重置停止标志
    led_stop_flag = false;

    while (!led_stop_flag) { // 循环直到收到停止信号
        // 执行中检测开关状态
        if (!led_function_enable) {
            rmt_send_ws2812_color(0, 0, 0);
            return;
        }
        
        // 渐亮阶段
        for (uint32_t i = 0; i < total_steps && !led_stop_flag; i++) {
            if (!led_function_enable) {
                rmt_send_ws2812_color(0, 0, 0);
                return;
            }
            const float rad = i * rad_step;
            float sin_val = sin(rad);
            
            sin_val = pow(sin_val, BREATH_SMOOTH_FACTOR);
            uint8_t brightness = (uint8_t)(sin_val * BREATH_MAX_BRIGHTNESS);

            // 平滑亮度变化
            if (abs((int)brightness - (int)last_bright) > 1) {
                brightness = last_bright + (brightness > last_bright ? 1 : -1);
            }
            last_bright = brightness;

            // 输出对应颜色
            if (color == BREATH_COLOR_RED) {
                rmt_send_ws2812_color(brightness, 0, 0);
            } else {
                rmt_send_ws2812_color(0, 0, brightness);
            }

            vTaskDelay(pdMS_TO_TICKS(BREATH_STEP_MS));
        }

        // 渐暗阶段
        for (uint32_t i = total_steps; i > 0 && !led_stop_flag; i--) {
            if (!led_function_enable) {
                rmt_send_ws2812_color(0, 0, 0);
                return;
            }
            const float rad = i * rad_step;
            float sin_val = sin(rad);
            
            sin_val = pow(sin_val, BREATH_SMOOTH_FACTOR);
            uint8_t brightness = (uint8_t)(sin_val * BREATH_MAX_BRIGHTNESS);

            // 平滑亮度变化
            if (abs((int)brightness - (int)last_bright) > 1) {
                brightness = last_bright + (brightness > last_bright ? 1 : -1);
            }
            last_bright = brightness;

            // 输出对应颜色
            if (color == BREATH_COLOR_RED) {
                rmt_send_ws2812_color(brightness, 0, 0);
            } else {
                rmt_send_ws2812_color(0, 0, brightness);
            }

            vTaskDelay(pdMS_TO_TICKS(BREATH_STEP_MS));
        }

        // 暗态停留（可选）
        if (!led_stop_flag && led_function_enable) {
            rmt_send_ws2812_color(0, 0, 0);
            vTaskDelay(pdMS_TO_TICKS(BREATH_DARK_OFF_MS));
        }
    }

    // 退出循环后强制熄灭
    rmt_send_ws2812_color(0, 0, 0);
}
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
void app_main(void) {
    ESP_LOGI(TAG, "=== CH9350 键鼠切换+LED系统启动 ===");

    // 初始化信号量
    ledSemaphore = xSemaphoreCreateBinary();

    // 初始化UART
    uart_config();

    // 初始化GPIO中断
    gpio_interrupt_config();

    // 初始化RMT和LED
    rmt_ws2812_init();
    xTaskCreate(led_control_task, "led_control", 8192, NULL, 5, NULL); // LED控制任务

    // 创建K3长按检测任务
    xTaskCreate(k3_long_press_detect_task, "k3_long_press", 2048, NULL, 4, NULL);

    // 新增：创建UART转发独立任务（低优先级，降低主任务负载）
    xTaskCreate(uart_forward_task, "uart_forward", 4096, NULL, 1, NULL);

    // 简化后的主循环：仅阻塞等待按键事件，释放CPU给IDLE任务
    while (1) {
        if (switchSemaphore && xSemaphoreTake(switchSemaphore, portMAX_DELAY) == pdTRUE) {
            if (triggerGpio == K1_GPIO) {
                switchConnection();
            } else if (triggerGpio == K2_GPIO) {
                toggleMouseMiddleFunc();
            } else if (triggerGpio == K3_GPIO) { // 处理K3短按
                toggleLedFunction();
            }
            triggerGpio = GPIO_NUM_NC;
        }
    }
}

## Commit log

2026-01-14 Repair### ❓ Frequently Asked Questions (FAQ)
2026-01-14 change Control Wiring
2026-01-14 add 3D Case Rendering
2026-01-14 add 3D Case Rendering1
2026-01-14 add 3D Case Rendering2
2026-01-14 add 3D Case Rendering3
2026-01-14 add 3D Case Rendering4
2026-01-14 add 3D Case Rendering 5
2026-01-14 add 3D Case Rendering 6
2026-01-15 ESP32 .gitignore
    Add ESP32 project dedicated .gitignore - filter build products and temporary files
2026-01-15 edit complete
    [box-Pocket008 (Meshed).stl, box.FCStd, box_cover_1-Pocket008 (Meshed)001.stl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]
